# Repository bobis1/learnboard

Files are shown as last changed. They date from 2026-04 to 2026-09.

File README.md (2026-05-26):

# Learnboard
Learnboard is a midi keyboard that I designed to "get my foot through the door" of creating hardware projects. This keyboard has 8 keys(16 physical switches). This keyboard has the feature to load "songs" into it. This keyboard also has LEDs that are under each of the 8 keys. These will light up whenyou hit the key or if the song that is loaded requires it.

## Features
* Freeplay mode
* Song loading/play-along mode
* Key Acceleration detection

## PCB
The learnboard's PCB has 2 layers.
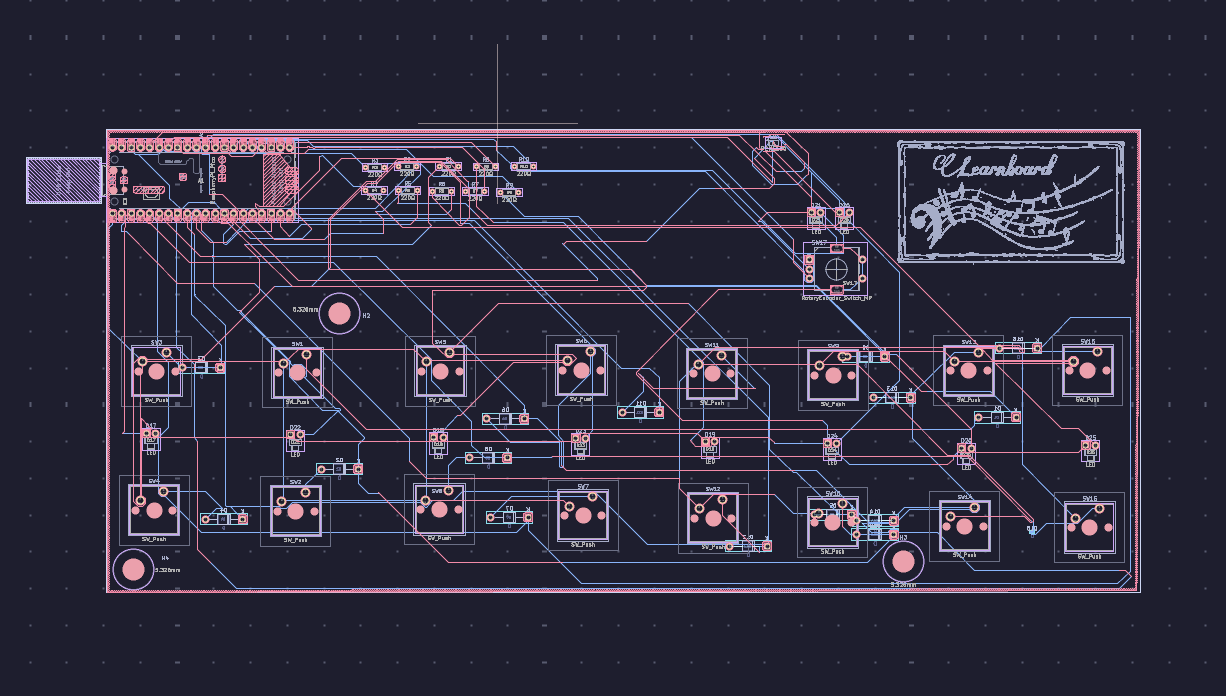
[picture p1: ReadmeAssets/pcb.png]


Here is the schematic for the PCB
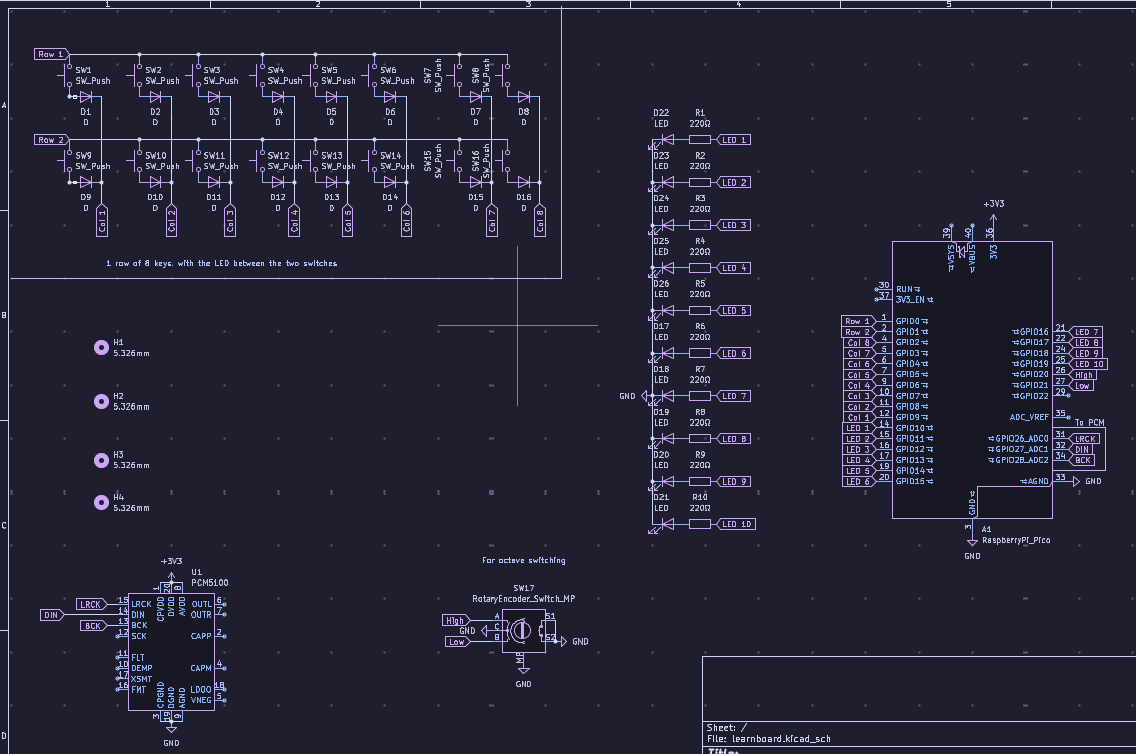
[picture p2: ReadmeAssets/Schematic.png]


Here is a 3D model of the pcb
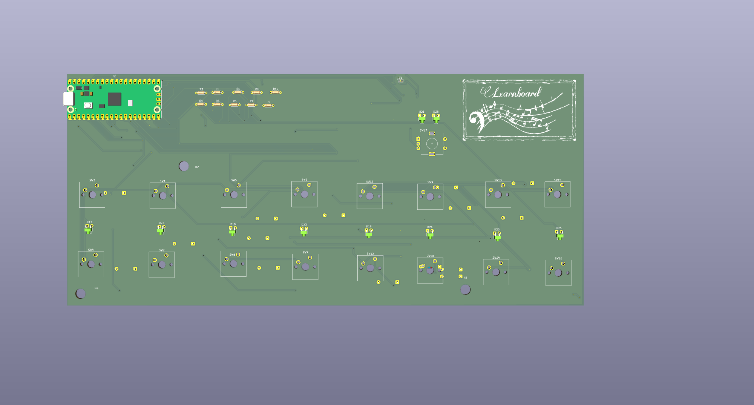
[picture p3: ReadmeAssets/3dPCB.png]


## Usage
To use the learnboard in the most basic context you simply hit the keys and the corresponding LED on that key will light up. To use the non freeplay mode you must use the webui that is inside the respective folder(This is a html document). From there you can adjust many things with the learnboard(Such as volume). The song loading works by loading .json files through the webui. To connect the midi keyboard to the webui you have to connect the midi keyboard to your computer. Then click the connect button on the connect window(These windows are partially based on the webos jam).

## Flashing
You can get the firmwware from the firmware folder of the repo. For this you can follow the circuit python tutorial for the board here: https://circuitpython.org/board/raspberry_pi_pico/ .

## Assembly
(When I actually have everything I will have images)
To assemble the learnboard you must first 3d print the case along with it's connectors. You need to print both parts of Case.step and caseTop.step. You need to print 2 Connector.step parts and 2 ConnectorWedge.step parts(This is if you are using printed connectors to connect the top and bottom of the case). You need 4 prints of teh PrintConnector.step file. When you have these printed slot the PrintConnectors into their respective bowtie slots in the cases.
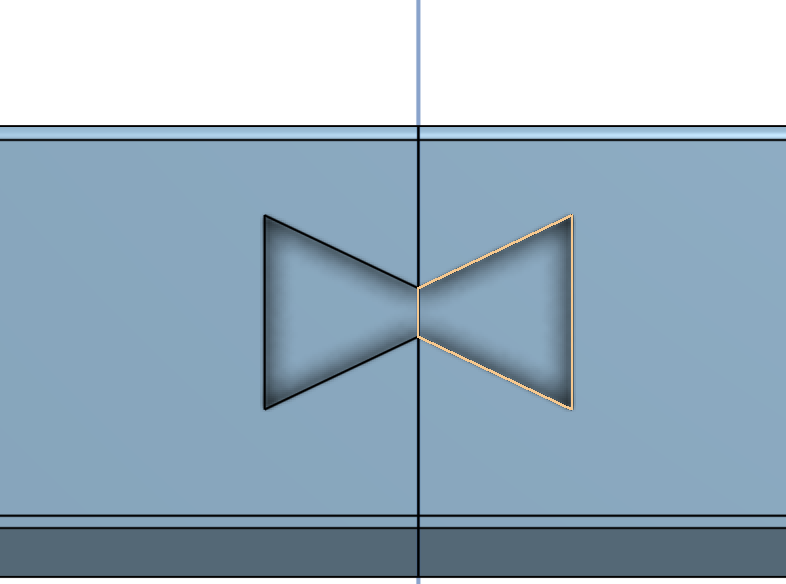
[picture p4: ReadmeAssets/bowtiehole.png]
(Looks like this). If you are using the printed connectors slot the Connector.step results into the two holes on the cases.Then put the wedge up the fork of the connector.

## Case
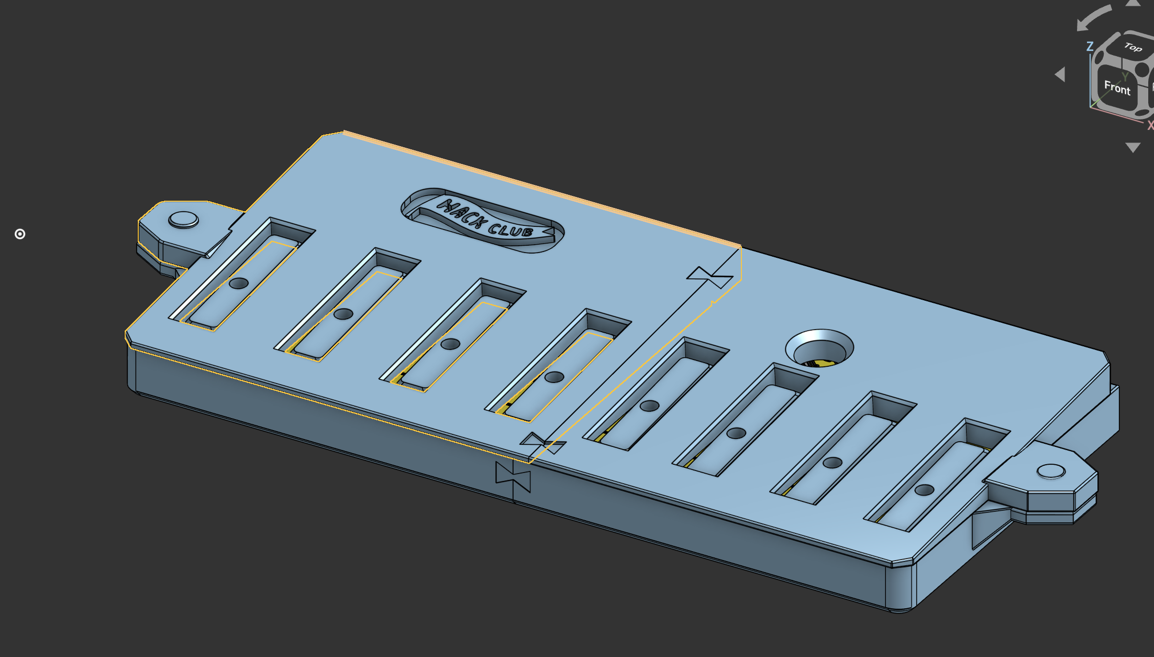
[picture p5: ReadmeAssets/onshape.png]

The case can be printed in several pieces. To hold the case pieces that are printed seperately there are "bowtie" connectors to connect these. The connector for the case top and the case bottom can be printed however a machine screw can also be used for that purpose. The .step files will be in the CAD folder. When printing I split the case into four parts. Two of the parts are in the Case.step file and the other two are in the caseTop.step file
Here is the link to the onshape.
https://cad.onshape.com/documents/c06ae8a09bf7d6a8ae56adf7/w/ad5690a7cddb318995ea60e9/e/03d033c41fe9f6e94a9a3737

## BOM
Here is the BOM. I put n/a in place of anything that I already had.
| Id | Designator | Footprint | Quantity | Designation | Supplier and ref | Unit price | Total price |  | Component | Price |
| --- | --- | --- | --- | --- | --- | --- | --- | --- | --- | --- |
| 1 | D19,D18,D22,D25,D21,D23,D24,D26,D17,D20 | LED_D1.8mm_W1.8mm_H2.4mm_Horizontal_O1.27mm_Z1.6mm | 10 | LED | https://www.aliexpress.us/item/3256802958597906.html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 | $0.99 | $0.99 |  | LED | $0.99 |
| 2 | SW9,SW15,SW14,SW4,SW8,SW2,SW16,SW5,SW13,SW10,SW1,SW6,SW3,SW11,SW7,SW12 | SW_Cherry_MX_1.00u_PCB | 16 | SW_Push | https://www.adafruit.com/product/4955 | $0.70 | $12.65 |  | Key Switches | $12.65 |
| 3 | R10,R7,R2,R6,R5,R9,R8,R3,R1,R4 | R_Axial_DIN0204_L3.6mm_D1.6mm_P5.08mm_Horizontal | 10 | 220Ω | https://www.aliexpress.us/item/3256811723963477.html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 | $0.99 | $0.99 |  | Resistor | $0.99 |
| 4 | A1 | RaspberryPi_Pico_Common_Unspecified | 1 | RaspberryPi_Pico | https://www.sparkfun.com/raspberry-pi-pico.html?src=raspberrypii | $4.60 | $4.60 |  | Raspberry pi_pico | $4.60 |
| 5 | U1 | TSSOP-20_4.4x6.5mm_P0.65mm | 1 | PCM5100 | https://www.adafruit.com/product/6251 | $3.95 | $3.95 |  | PCM5100 | $3.95 |
| 6 | SW17 | RotaryEncoder_Alps_EC11E-Switch_Vertical_H20mm | 1 | RotaryEncoder_Switch_MP | https://www.aliexpress.us/item/3256805796844720.html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 | $0.99 | $0.99 |  | Rotary Encoder | $0.99 |
| 7 | D12,D11,D8,D7,D13,D3,D6,D16,D10,D15,D14,D4,D1,D9,D2,D5 | D_0201_0603Metric_Pad0.64x0.40mm_HandSolder | 16 | D | https://www.aliexpress.us/item/3256807405706559.html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 | $0.11 | $2.10 |  | Diodes | $2.10 |
|  |  |  |  |  |  |  |  |  | PCB | $18.20 |
|  |  |  |  |  |  |  |  |  | Shipping | $22.19 |
|  |  |  |  |  |  |  |  |  | Total | $65.67 |
The .csv file for the BOM can be found [here](ReadmeAssets/BOM.csv)

### Poster
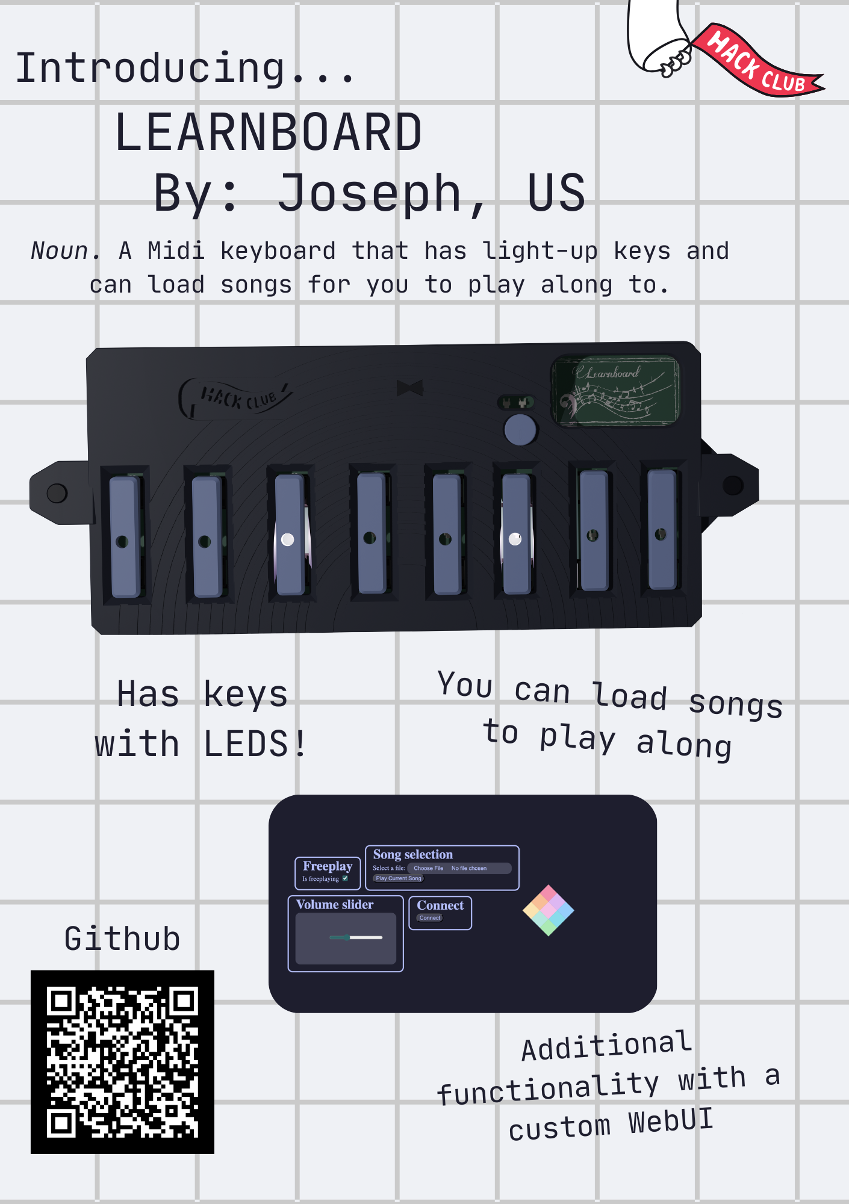
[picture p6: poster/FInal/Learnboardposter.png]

The .pdf file for the poster can be found [here](poster/Learnboardposter.pdf)

## References
https://blueprint.hackclub.com/starter-projects/midi
This is a project I got alot of the idea from.
https://jams.hackclub.com/batch/webOS
Where I got the ideas for the windows from

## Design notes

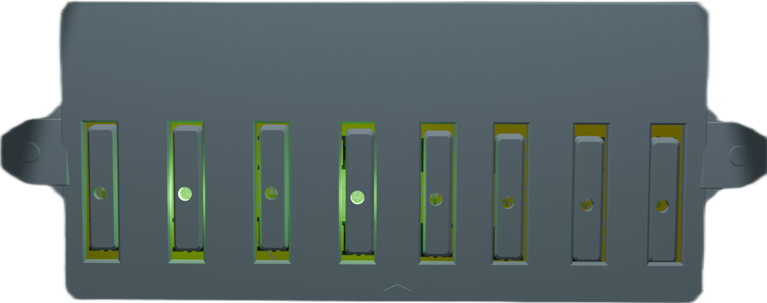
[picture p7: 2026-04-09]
poster/DraftRenders/FinalTrans.png

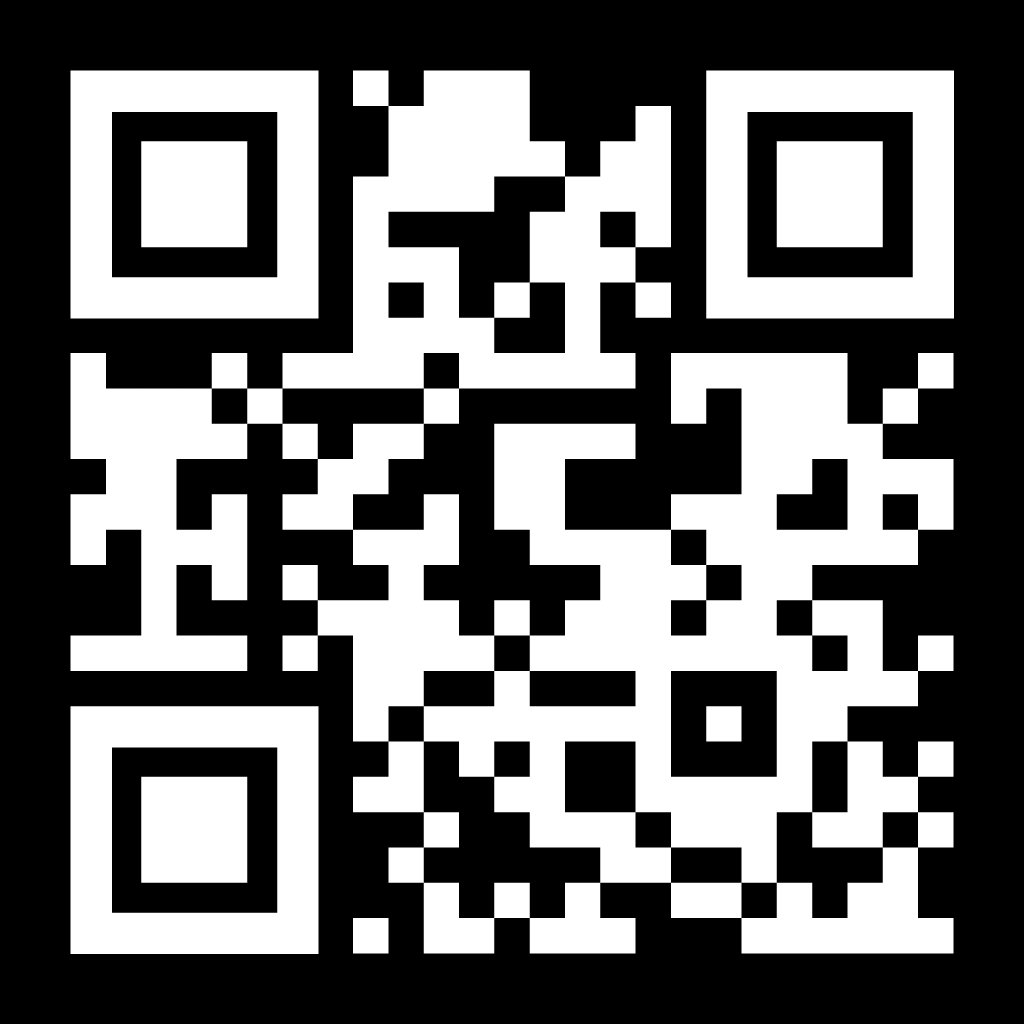
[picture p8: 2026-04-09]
poster/Posterassets/qr.png

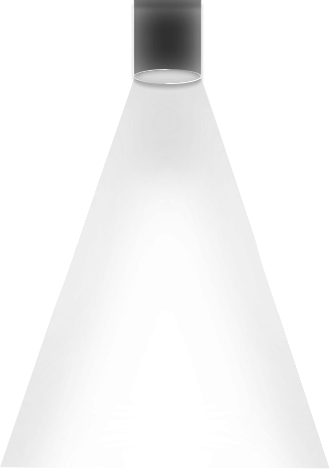
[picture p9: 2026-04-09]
poster/Posterassets/Light.png

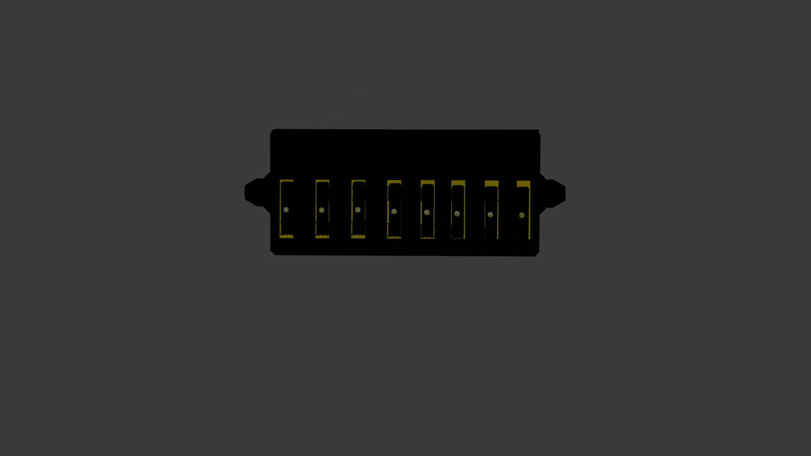
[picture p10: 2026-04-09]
poster/DraftRenders/Untitled.png

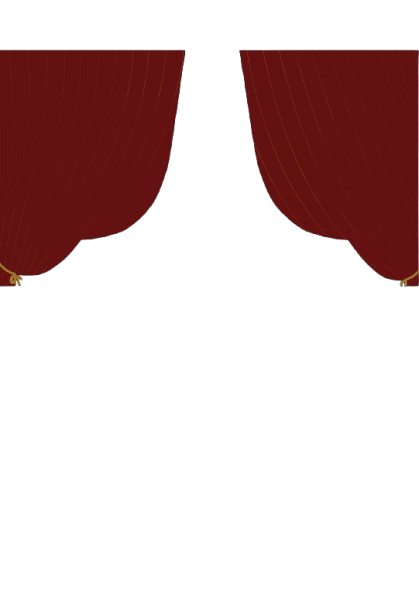
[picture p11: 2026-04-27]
poster/Posterassets/Learnboard_poster-removebg-preview.png

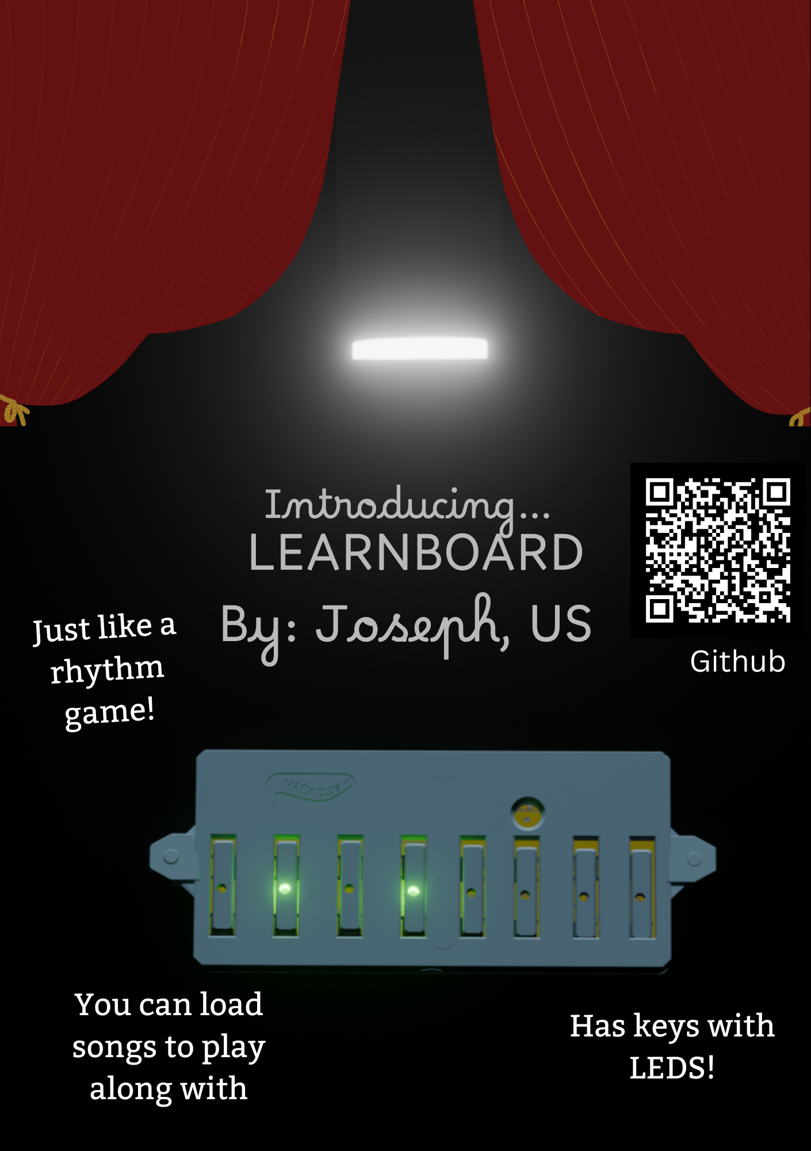
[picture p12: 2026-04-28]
poster/DraftRenders/Learnboardposter.png

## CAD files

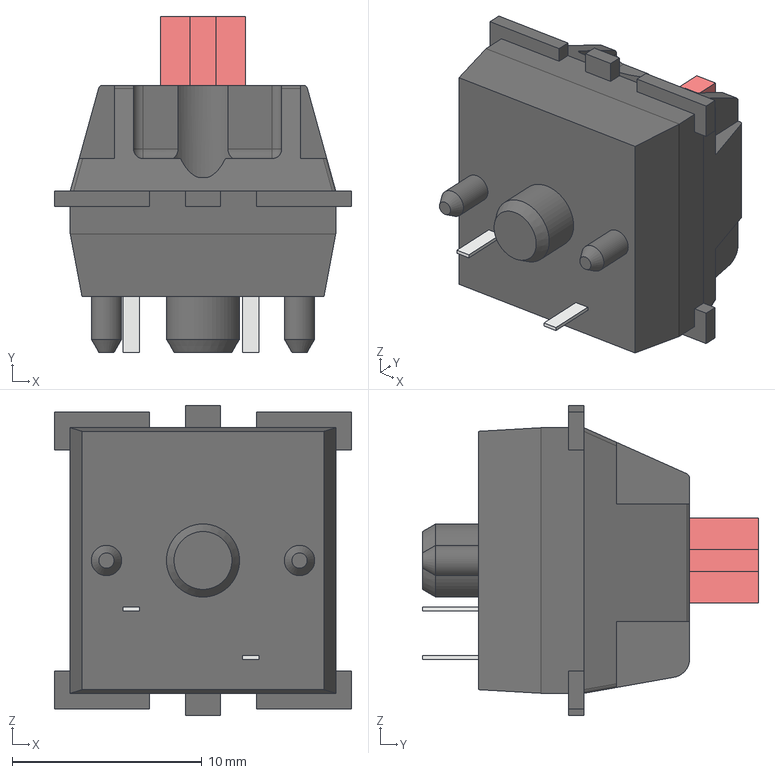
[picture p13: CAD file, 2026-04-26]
PCB/switch.step
15.6 x 17.7 x 16.3 mm

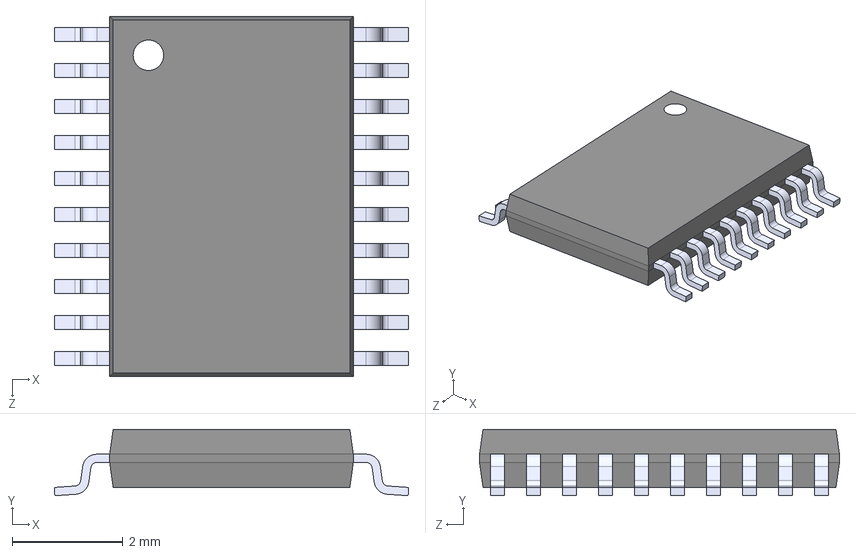
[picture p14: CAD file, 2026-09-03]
PCM5100APWR/PCM5100APWR.step
6.40 x 1.20 x 6.50 mm

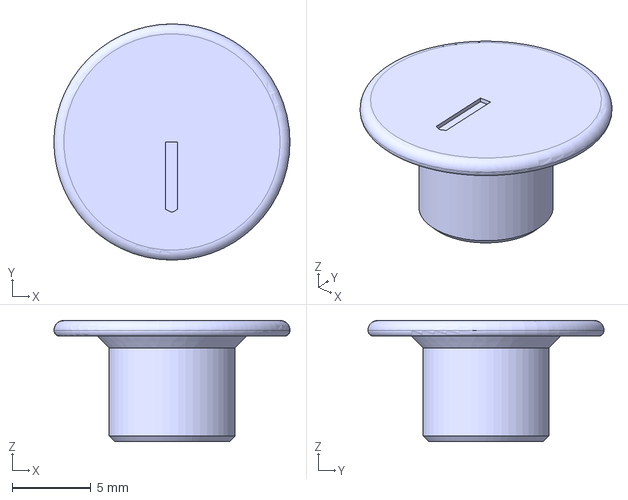
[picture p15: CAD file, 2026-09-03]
stepFiles/RotaryEncoderTop.step
15.0 x 15.0 x 7.70 mm

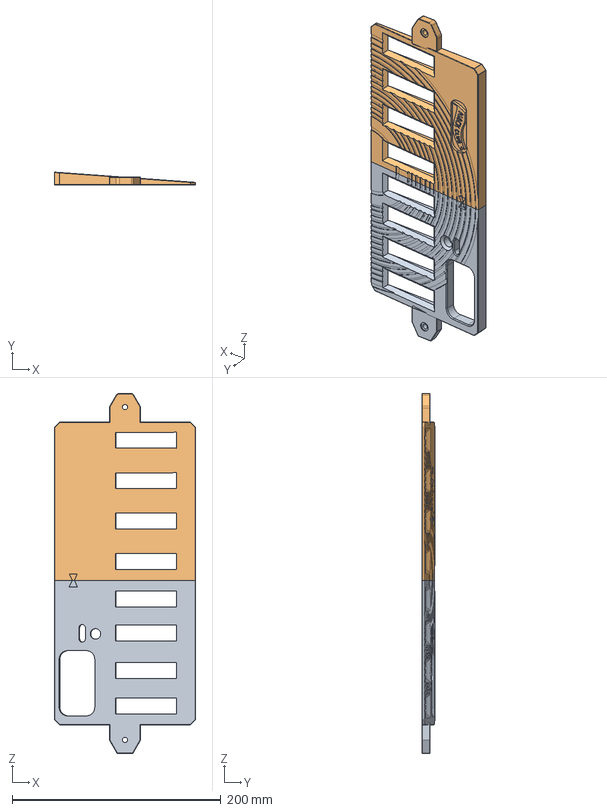
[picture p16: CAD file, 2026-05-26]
stepFiles/CaseTop.step
135.4 x 12.2 x 344.7 mm

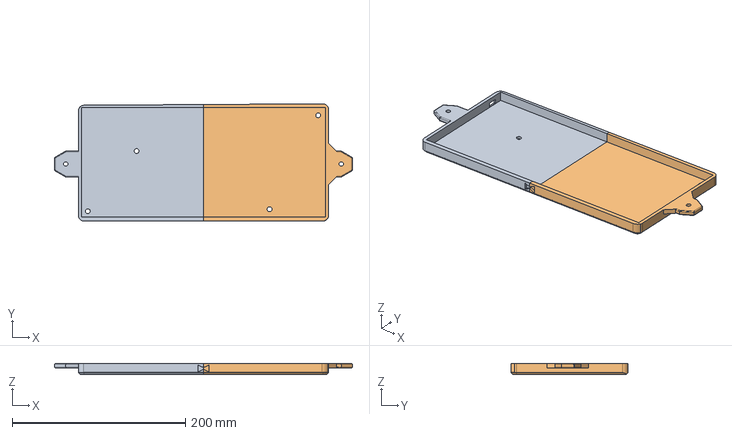
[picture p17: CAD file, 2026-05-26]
stepFiles/Case.step
344.1 x 135.5 x 12.5 mm

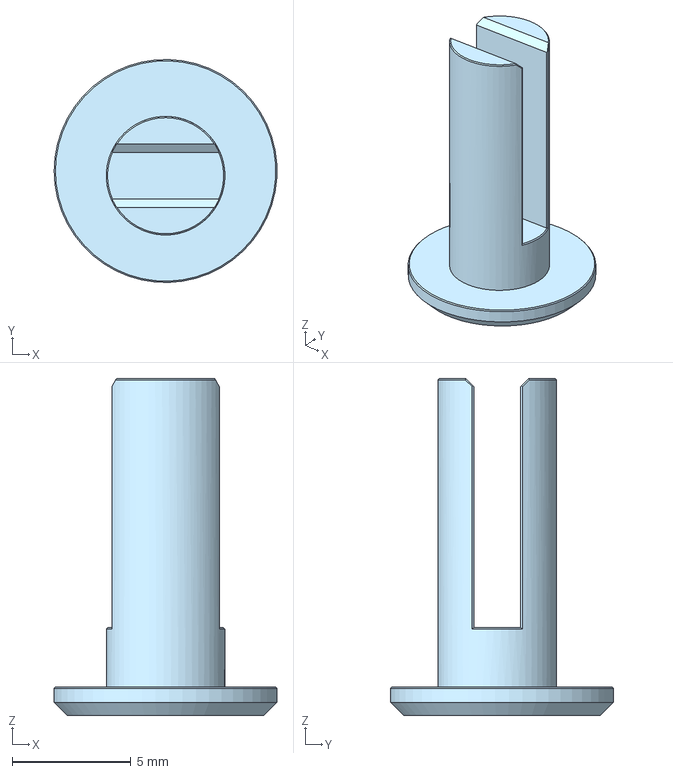
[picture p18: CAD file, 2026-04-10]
stepFiles/Connector.step
9.39 x 9.39 x 14.2 mm

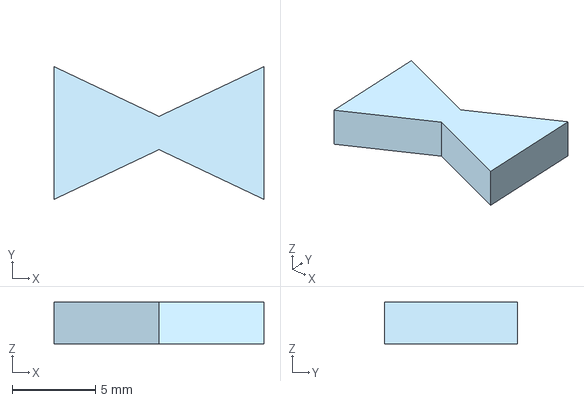
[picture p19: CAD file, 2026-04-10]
stepFiles/PrintConnector.step
12.6 x 8.00 x 2.50 mm

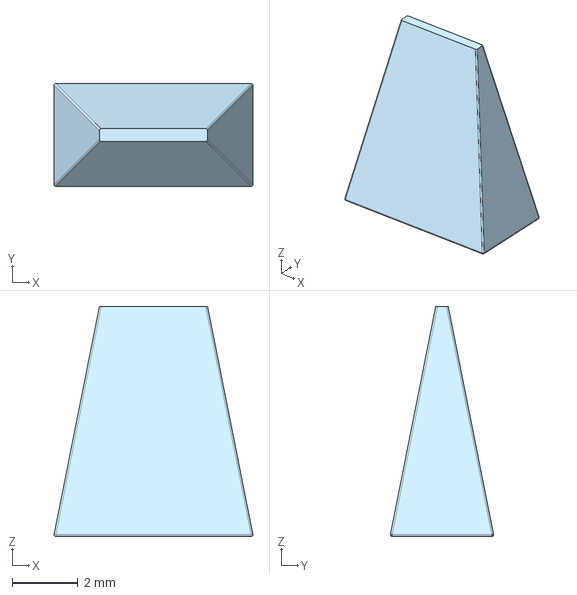
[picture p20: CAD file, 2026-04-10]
stepFiles/ConnectorWedge.step
6.05 x 3.14 x 7.00 mm

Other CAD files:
poster/LightRender.blend
stepFiles/Case.3mf
stepFiles/CaseTop.3mf
stepFiles/RotaryEncoderTop.3mf

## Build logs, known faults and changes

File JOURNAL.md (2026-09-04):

---
title: "Learnboard-build"
author: "Bobis"
description: "a midi keyboard that has the keys light up when you play them"
created_at: "2026-04-2"
---

# September 2: Sodered some of the basic components.

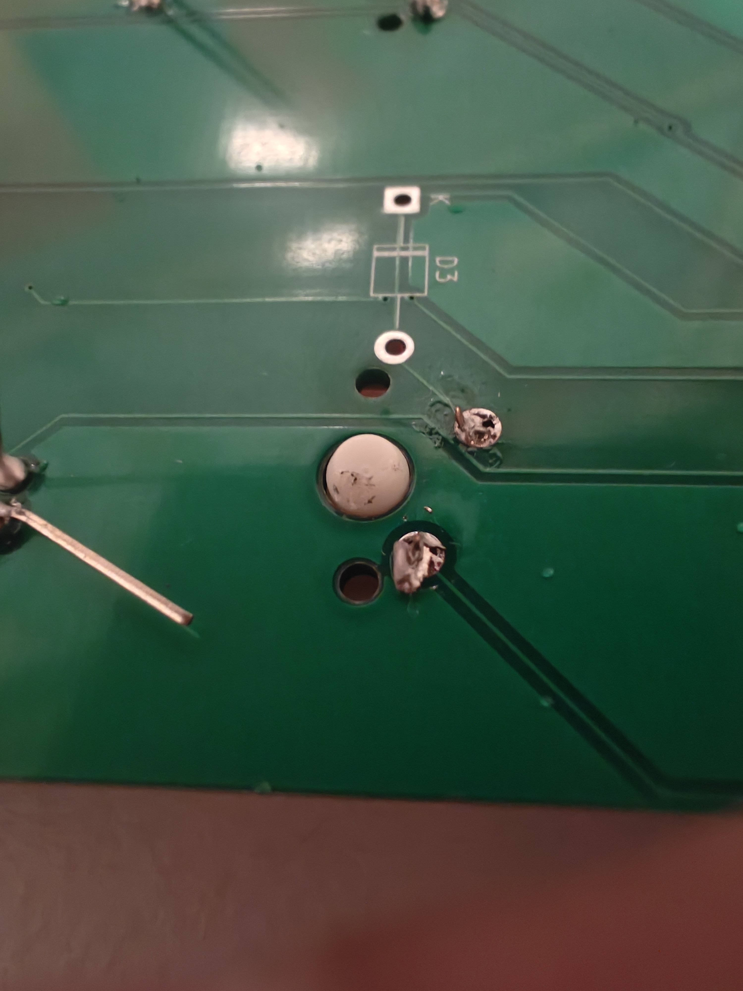
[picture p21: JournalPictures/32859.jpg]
BurntKeyswitch
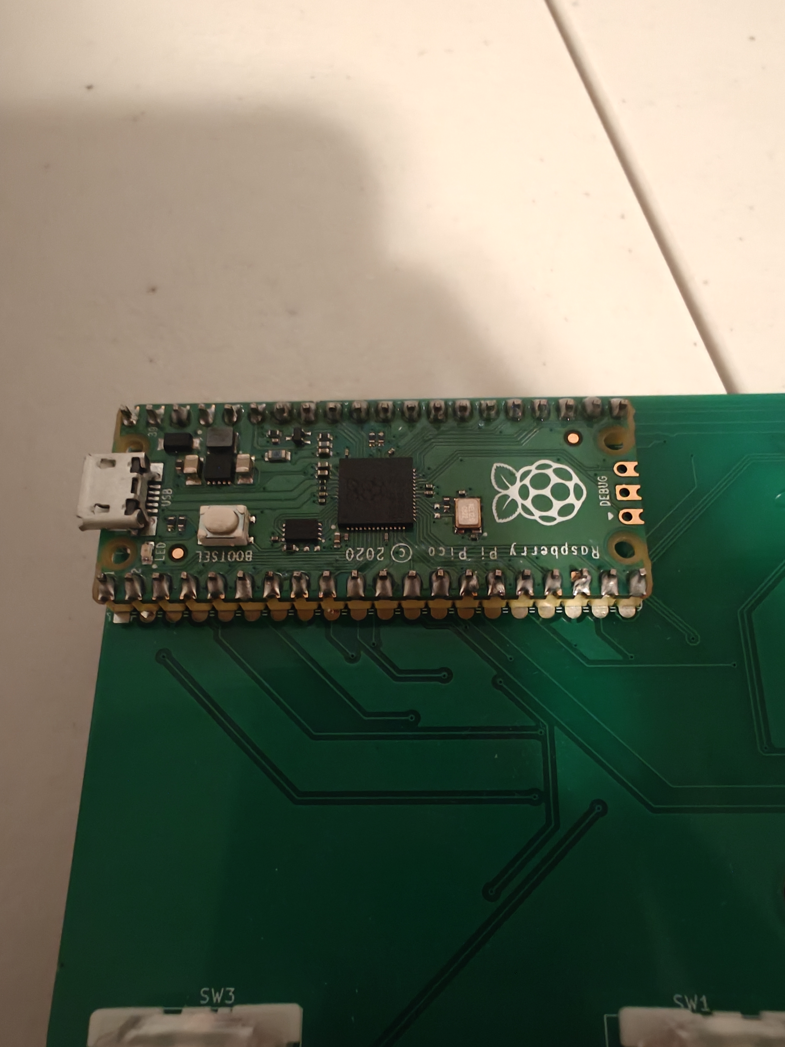
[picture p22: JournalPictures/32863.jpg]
rpPico
This devlog I worked on trying to soder all the components onto the pcb. This is my first time sodering so it did not go the best. I partially burnt one of the key switches, oops. . The resistors were very messy as well with the the footprint being too small to actually fit the resistor properly. The other than this I feel like my sodering on the raspberry pi pico was good enough that . Overall, this is not too bad. I really need to be more efficient in my time though.

-Recording links
https://lapse.hackclub.com/timelapse/0V47lkOwijM5
https://lapse.hackclub.com/timelapse/Xaw-gElLUrd_
https://lapse.hackclub.com/timelapse/J6UoXvX0RNCo
https://lapse.hackclub.com/timelapse/zv9pdq6mI1ch
https://lapse.hackclub.com/timelapse/Xwd5ic2uPJUL

**Total time spent: 1.56 hours**

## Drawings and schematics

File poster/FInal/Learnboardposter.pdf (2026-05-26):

Introducing...

# LEARNBOARD

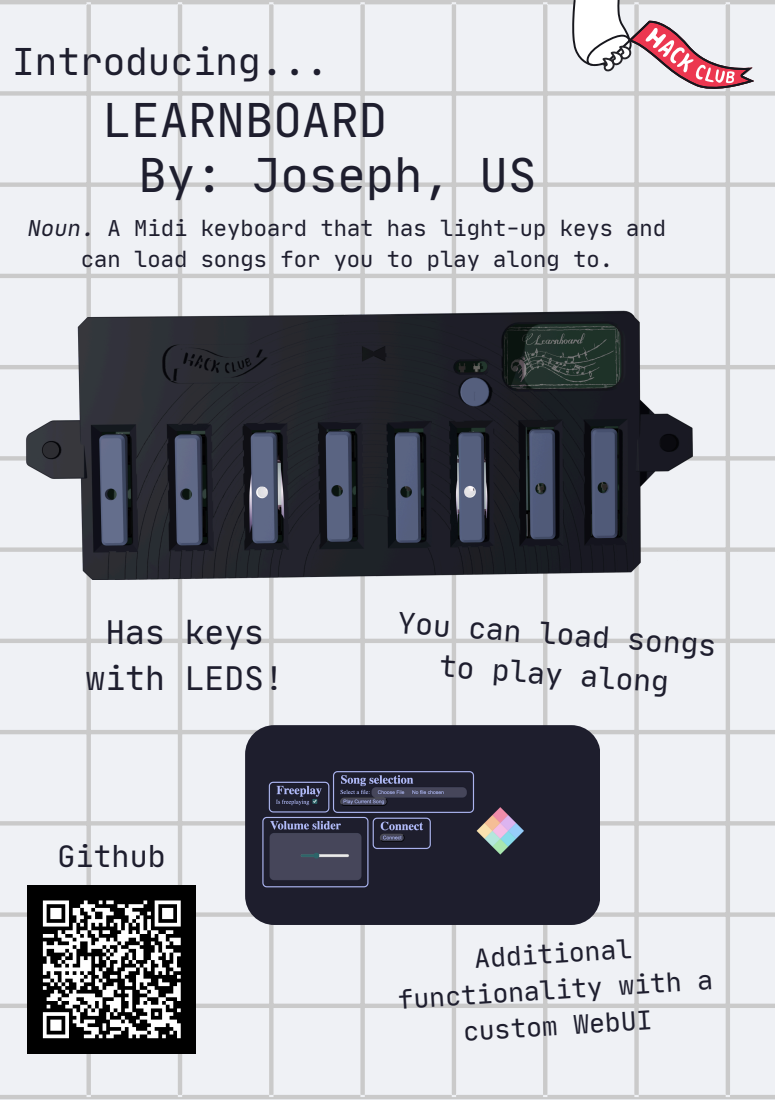
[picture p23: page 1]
By: Joseph,; Github; Additional functionality with a custom WebUI; Has; keys; with; LEDS!; Noun. A Midi keyboard that has light-up; keys and; can load songs; for you to play along to.

You can load songs

to play along

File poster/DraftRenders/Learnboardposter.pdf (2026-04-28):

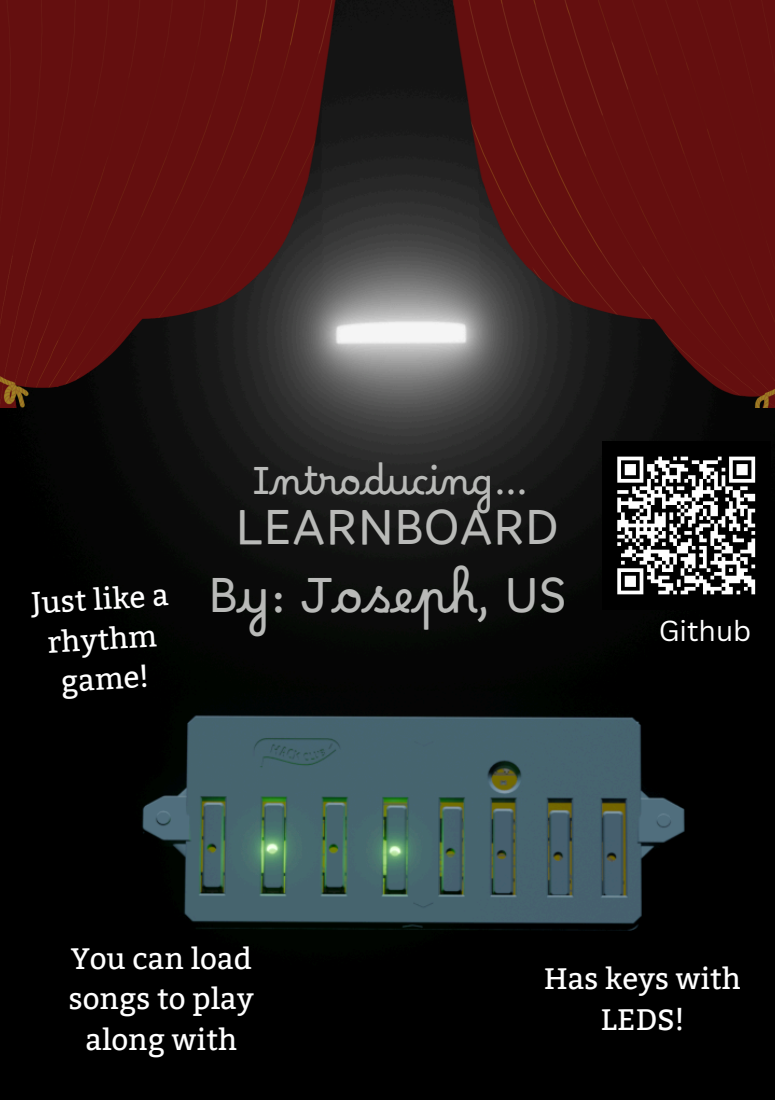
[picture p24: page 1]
Github; Just like a rhythm game!

Introducing...
LEARNBOARD
By: Joseph, US

You can load
songs to play
along with

Has keys with
LEDS!

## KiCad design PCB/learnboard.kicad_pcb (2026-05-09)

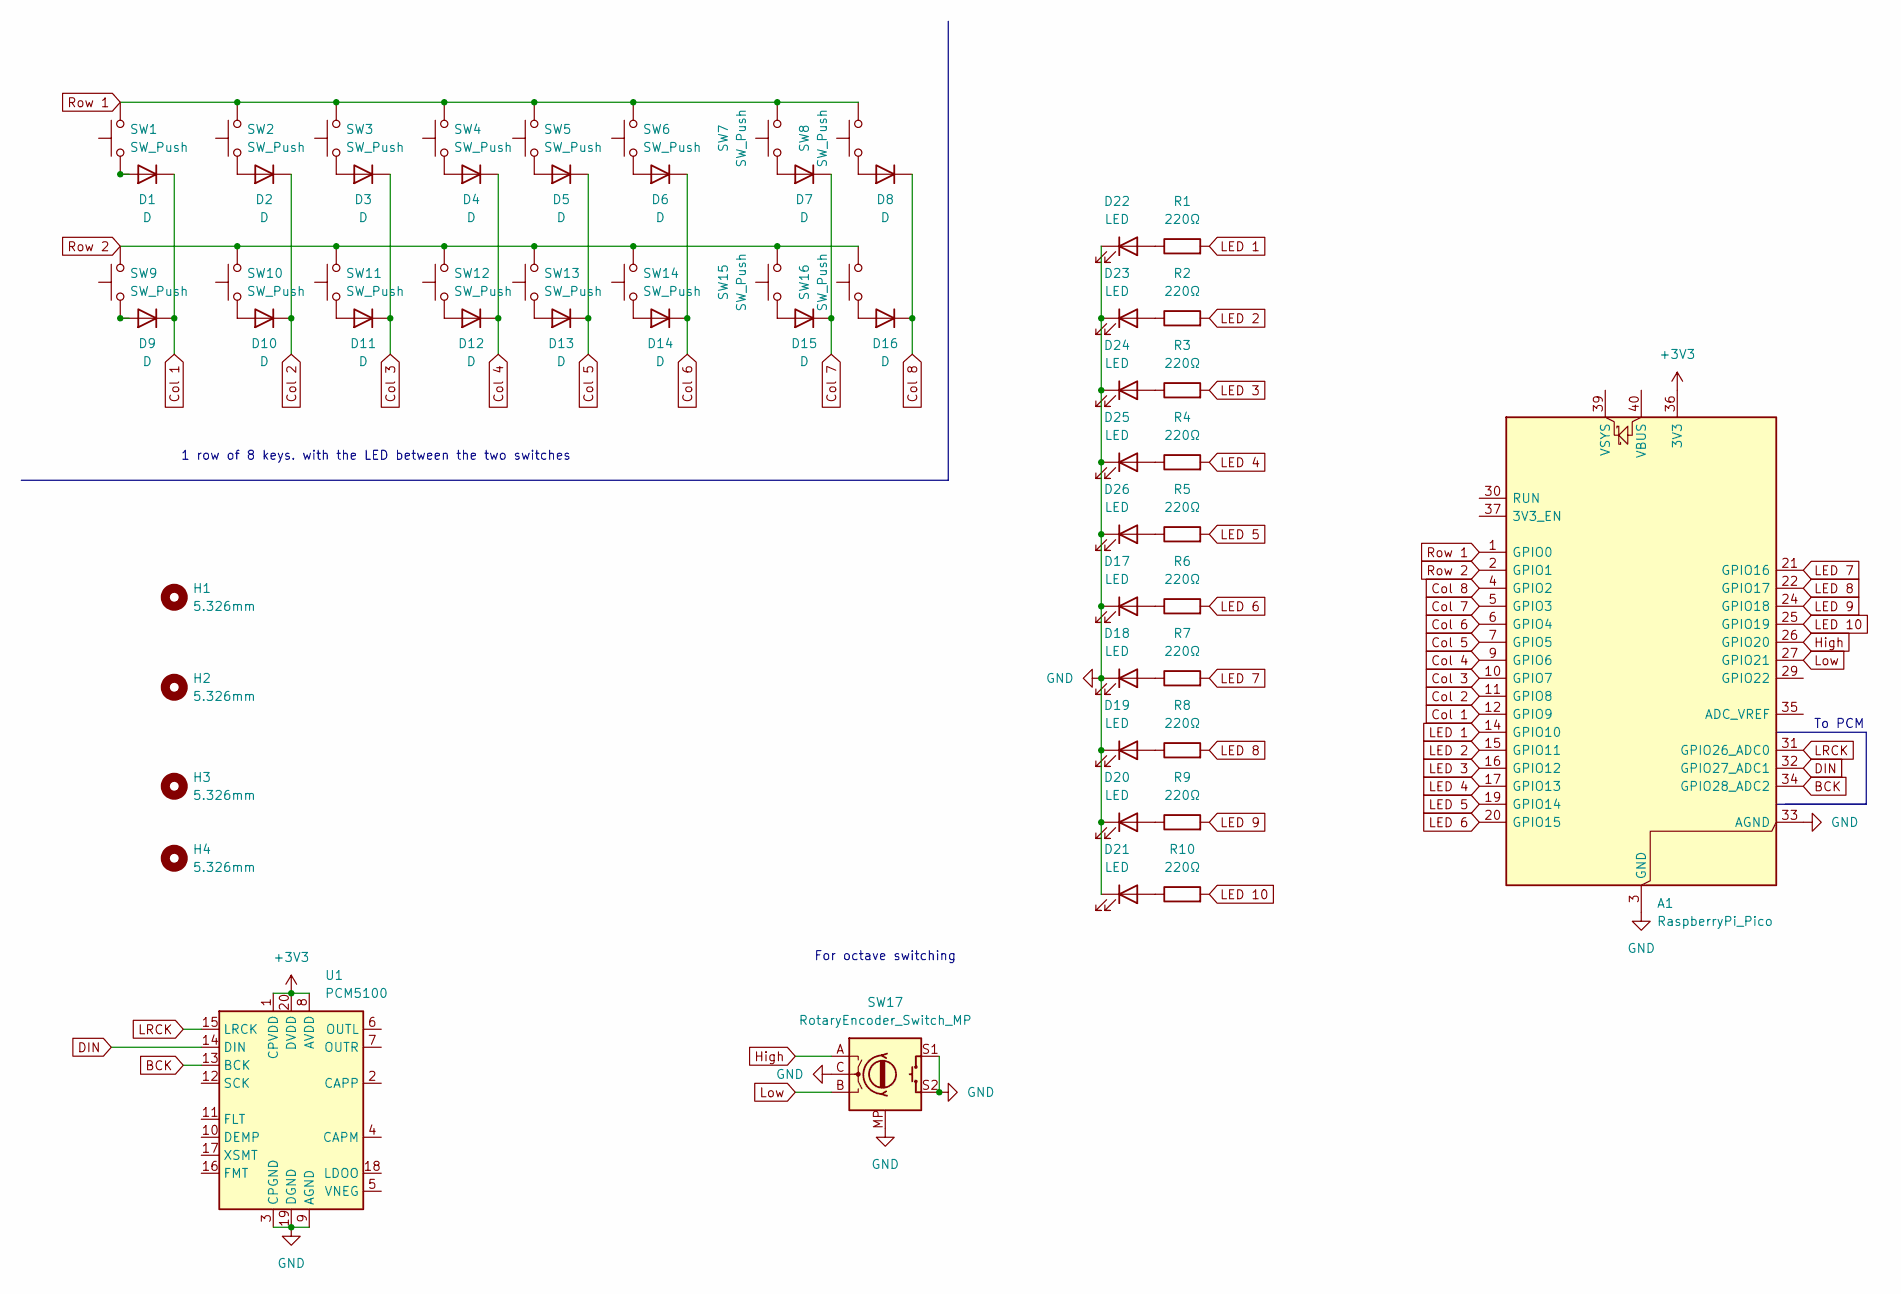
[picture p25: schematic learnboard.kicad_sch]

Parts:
A1: RaspberryPi_Pico; RaspberryPi_Pico_Common_Unspecified
D1, D2, D3, D4, D5, D6, D7, D8, D9, D10, D11, D12, D13, D14, D15, D16: D; D_0201_0603Metric
D17, D18, D19, D20, D21, D22, D23, D24, D25, D26: LED; LED_D1.8mm_W1.8mm_H2.4mm_Horizontal_O1.27mm_Z1.6mm
H1, H2, H3, H4: 5.326mm; MountingHole_5.5mm
R1, R2, R3, R4, R5, R6, R7, R8, R9, R10: 220Ω; R_Axial_DIN0204_L3.6mm_D1.6mm_P5.08mm_Horizontal
SW1, SW2, SW3, SW4, SW5, SW6, SW7, SW8, SW9, SW10, SW11, SW12, SW13, SW14, SW15, SW16: SW_Push; SW_Cherry_MX_1.00u_PCB
SW17: RotaryEncoder_Switch_MP; RotaryEncoder_Alps_EC11E-Switch_Vertical_H20mm
U1: PCM5100; Nexperia_WLCSP-15_2.37x1.17mm_Layout6x3_P0.4mmP0.8mm

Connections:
+3V3: A1.36 (3V3), U1.1 (CPVDD), U1.8 (AVDD), U1.20 (DVDD)
BCK: A1.34 (GPIO28_ADC2), U1.13 (BCK)
Col 1: A1.12 (GPIO9), D1.1 (K), D9.1 (K)
Col 2: A1.11 (GPIO8), D2.1 (K), D10.1 (K)
Col 3: A1.10 (GPIO7), D3.1 (K), D11.1 (K)
Col 4: A1.9 (GPIO6), D4.1 (K), D12.1 (K)
Col 5: A1.7 (GPIO5), D5.1 (K), D13.1 (K)
Col 6: A1.6 (GPIO4), D6.1 (K), D14.1 (K)
Col 7: A1.5 (GPIO3), D7.1 (K), D15.1 (K)
Col 8: A1.4 (GPIO2), D8.1 (K), D16.1 (K)
DIN: A1.32 (GPIO27_ADC1), U1.14 (DIN)
GND: A1.3 (GND), A1.8 (GND), A1.13 (GND), A1.18 (GND), A1.23 (GND), A1.28 (GND), A1.33 (AGND), A1.38 (GND), D17.1 (K), D18.1 (K), D19.1 (K), D20.1 (K), D21.1 (K), D22.1 (K), D23.1 (K), D24.1 (K), D25.1 (K), D26.1 (K), SW17.C, SW17.MP, SW17.S1, SW17.S2, U1.3 (CPGND), U1.9 (AGND), U1.19 (DGND)
High: A1.26 (GPIO20), SW17.A
LED 1: A1.14 (GPIO10), R1.2
LED 2: A1.15 (GPIO11), R2.2
LED 3: A1.16 (GPIO12), R3.2
LED 4: A1.17 (GPIO13), R4.2
LED 5: A1.19 (GPIO14), R5.2
LED 6: A1.20 (GPIO15), R6.2
LED 7: A1.21 (GPIO16), R7.2
LED 8: A1.22 (GPIO17), R8.2
LED 9: A1.24 (GPIO18), R9.2
LED 10: A1.25 (GPIO19), R10.2
LRCK: A1.31 (GPIO26_ADC0), U1.15 (LRCK)
Low: A1.27 (GPIO21), SW17.B
unnamed: D1.2 (A), SW1.1
unnamed: D2.2 (A), SW2.1
unnamed: D3.2 (A), SW3.1
unnamed: D4.2 (A), SW4.1
unnamed: D5.2 (A), SW5.1
unnamed: D6.2 (A), SW6.1
unnamed: D7.2 (A), SW7.1
unnamed: D8.2 (A), SW8.1
unnamed: D9.2 (A), SW9.1
unnamed: D10.2 (A), SW10.1
unnamed: D11.2 (A), SW11.1
unnamed: D12.2 (A), SW12.1
unnamed: D13.2 (A), SW13.1
unnamed: D14.2 (A), SW14.1
unnamed: D15.2 (A), SW15.1
unnamed: D16.2 (A), SW16.1
unnamed: D17.2 (A), R6.1
unnamed: D18.2 (A), R7.1
unnamed: D19.2 (A), R8.1
unnamed: D20.2 (A), R9.1
unnamed: D21.2 (A), R10.1
unnamed: D22.2 (A), R1.1
unnamed: D23.2 (A), R2.1
unnamed: D24.2 (A), R3.1
unnamed: D25.2 (A), R4.1
unnamed: D26.2 (A), R5.1
Row 1: A1.1 (GPIO0), SW1.2, SW2.2, SW3.2, SW4.2, SW5.2, SW6.2, SW7.2, SW8.2
Row 2: A1.2 (GPIO1), SW9.2, SW10.2, SW11.2, SW12.2, SW13.2, SW14.2, SW15.2, SW16.2

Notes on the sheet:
To PCM
For octave switching
1 row of 8 keys. with the LED between the two switches

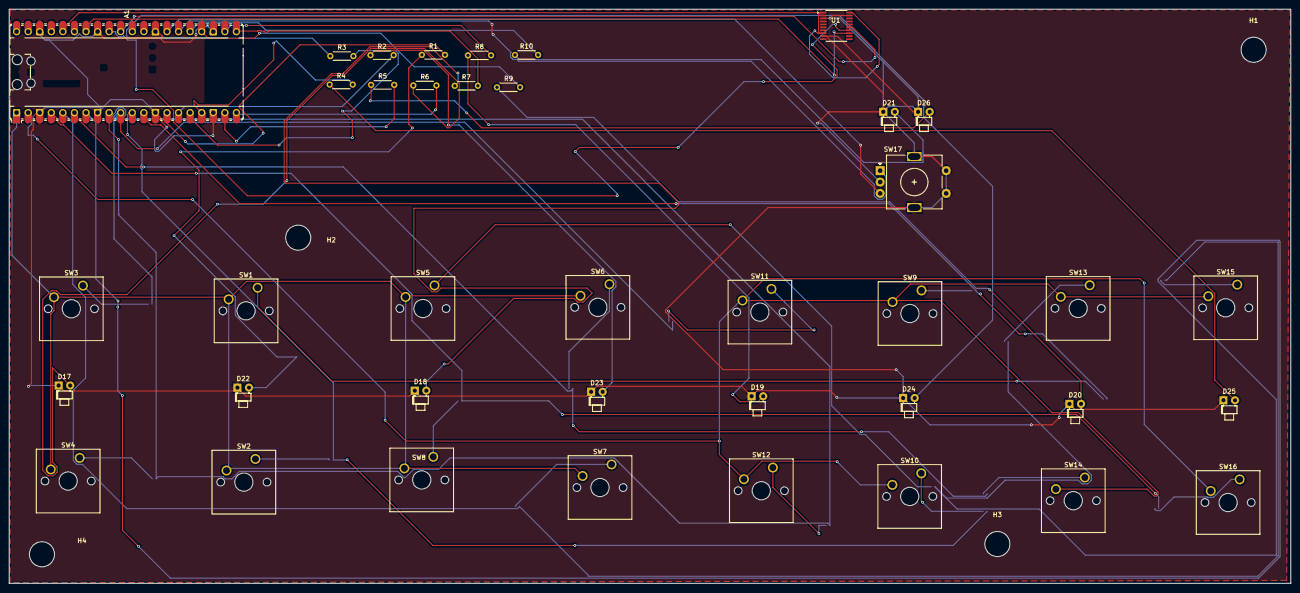
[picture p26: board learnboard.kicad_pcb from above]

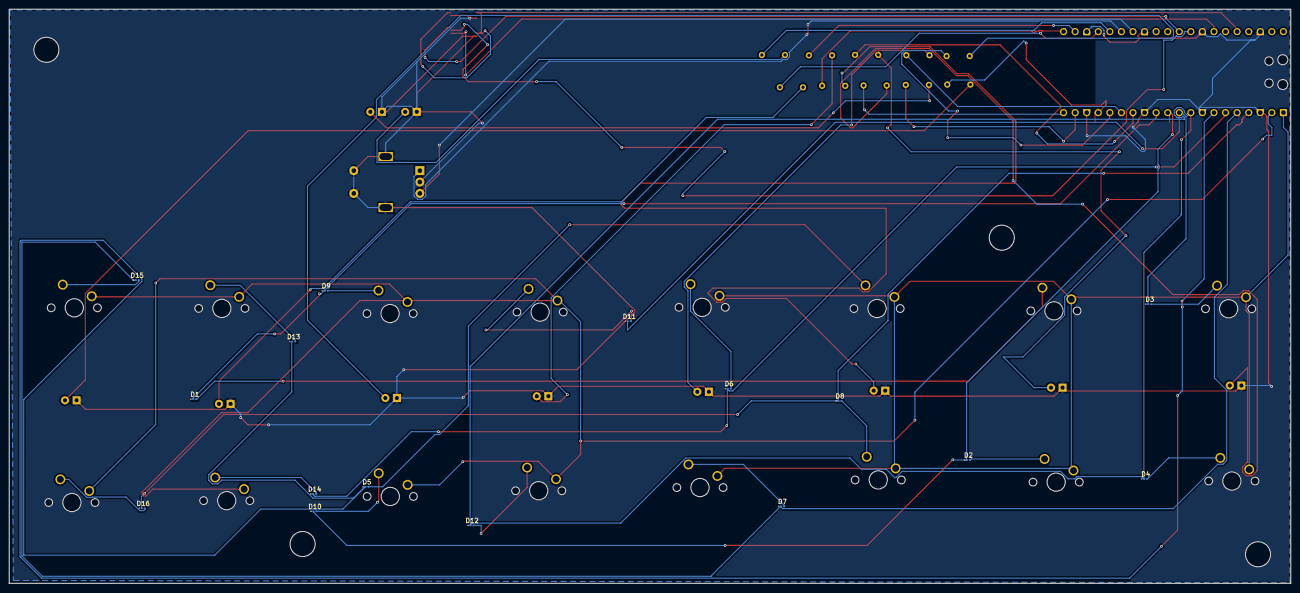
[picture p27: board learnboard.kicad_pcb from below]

Board: 2 copper layers, 281.4 x 126.0 mm, 59 parts (16 on the bottom side), 53 nets.

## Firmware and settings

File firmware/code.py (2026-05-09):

import board
import keypad
import digitalio
import audiobusio
import audiocore
import time
import rotaryio
import audiomixer
import usb_cdc

import usb_midi
import adafruit_midi
from adafruit_midi.note_off import NoteOff
from adafruit_midi.note_on import NoteOn
from adafruit_midi.pitch_bend import PitchBend

dac = audiobusio.I2SOut(bit_clock=board.GPIO1028_ADC2, word_select=board.GPIO1028_ADC0, data= board.GPIO1028_ADC1)
mixer = audiomixer.Mixer(voice_count=1, sample_rate=22050, channels=1, bits_per_sample=16, samples_per_frame=512)
dac.play(mixer)

rows = [board.GPIO100, board.GPIO101, board.GPIO102]
cols = [board.GPIO103, board.GPIO104, board.GPIO105, board.GPIO106, board.GPIO107, board.GPIO108, board.GPIO109]

wavef0 = open("pianoC", "rb")
wavef1 = open("pianoD", "rb")
wavef2 = open("pianoE", "rb")
wavef3 = open("pianoF", "rb")
wavef4 = open("pianoG", "rb")
wavef5 = open("pianoA", "rb")
wavef6 = open("pianoB", "rb")
wavef7 = open("pianoC1", "rb")

wav0 = audiocore.WaveFile(wavef0)
wav1 = audiocore.WaveFile(wavef1)
wav2 = audiocore.WaveFile(wavef2)
wav3 = audiocore.WaveFile(wavef3)
wav4 = audiocore.WaveFile(wavef4)
wav5 = audiocore.WaveFile(wavef5)
wav6 = audiocore.WaveFile(wavef6)
wav7 = audiocore.WaveFile(wavef7)

SW1 = 9
SW2 = 10
SW3 = 11
SW4 = 12
SW5 = 13
SW6 = 14
SW7 = 15
SW8 = 16
SW9 = 17
SW10 = 18
SW11 = 19
SW12 = 20
SW13 = 21
SW14 = 22
SW15 = 23
SW16 = 24

iswav0Playing = False
iswav1Playing = False
iswav2Playing = False
iswav3Playing = False
iswav4Playing = False
iswav5Playing = False
iswav6Playing = False
iswav7Playing = False

L = []

L.append(digitalio.DigitalInOut(board.GPIO10))
L.append(digitalio.DigitalInOut(board.GPIO11))
L.append(digitalio.DigitalInOut(board.GPIO12))
L.append(digitalio.DigitalInOut(board.GPIO13))
L.append(digitalio.DigitalInOut(board.GPIO14))
L.append(digitalio.DigitalInOut(board.GPIO15))
L.append(digitalio.DigitalInOut(board.GPIO16))
L.append(digitalio.DigitalInOut(board.GPIO17))
L.append(digitalio.DigitalInOut(board.GPIO18))
L.append(digitalio.DigitalInOut(board.GPIO19))


nextKeys = []
nextKeyTimes = []

i = 0

encoder = rotaryio.IncrementalEncoder(board.GPIO20, board.GPIO21)

Freeplay = True


ticks = 20.0

currentTime = time.monotonic()


playingTime = 0.2
accuracy = float


usb_cdc.enable(True)

startTimes = {}

KeyGroups = {
    9:7,
    10:18,
    11:19,
    12:20,
    13:21,
    14:22,
    15:23,
    16:24

}

KeyGroupsToLED = {
    1:5,
    2:0,
    3:6,
    4:1,
    5:7,
    6:2,
    7:8,
    8:3
}

matrix = keypad.KeyMatrix(row_pins=(board.GPIO100, board.GPIO101), column_pins=(board.GPIO109, board.GPIO108, board.GPIO107, board.GPIO106, board.GPIO105, board.GPIO104, board.GPIO103, board.GPIO102))

led_off_times = [0.0] * 10
last_activated_led = 0

while True:

    currentTime = time.monotonic()
    event = matrix.events.get()
    position = encoder.position

    if position != enc_pos:
        enc_pos = position
        volume = position/20.0
        volume = max(0.0, min(1.0, volume))
        mixer.voice.level = volume

    if usb_cdc.console.in_waiting > 1:
        raw_data = usb_cdc.console.readline()
        line = str(raw_data, "utf-8").strip()
        line = str(raw_data, "utf-8").strip()
        if line.startswith("V"):
            try:
                new_vol = float(line[1:]) / 100
                mixer.voice[0].level = new_vol
            except:
                pass
        if line.startswith("F"):
            try:
                Freeplay = bool(line[1:])
            except:
                pass
        if line.startswith("K"):
            try:
                #The user puts in key group
                keyGroup = int(line[1:])
                KeyGroupsToLED[keyGroup].value = True
            except:
                pass
        if line.startswith("T"):
            try:
                #user puts the time in seconds.
                duration = float(line[1:])
                nextKeyTimes[i] = duration + currentTime
            except:
                pass



    if Freeplay == False:
        for idx in range(len(L)):
            if led_off_times[idx] != 0 and currentTime >= led_off_times[idx]:
                L[idx].value = False
                led_off_times[idx] = 0


    if event:
        print(event.key_number, event.pressed)
        if Freeplay:
            match event.key_number:
                case 9:
                    if iswav0Playing == False:
                        L[5].value = True
                        startTimes[9] = time.monotonic()
                        #iswav0Playing = True
                case 10:
                    if iswav1Playing == False:
                        startTimes[10] = time.monotonic()
                        L[0].value = True
                        #iswav1Playing = True
                case 11:
                    if iswav2Playing == False:
                        L[6].value = True
                        startTimes[11] = time.monotonic()
                        #iswav2Playing = True
                case 12:
                    if iswav3Playing == False:
                        L[1].value = True
                        startTimes[12] = time.monotonic()
                        #iswav3Playing = True
                case 13:
                    if iswav4Playing == False:
                        L[7].value = True
                        startTimes[13] = time.monotonic()
                        #iswav4Playing = True
                case 14:
                    if iswav5Playing == False:
                        L[2].value = True
                        startTimes[14] = time.monotonic()
                       # iswav5Playing = True
                case 15:
                    if iswav6Playing == False:
                        L[8].value = True
                        startTimes[15] = time.monotonic()
                        #iswav6Playing = True
                case 16:
                    if iswav7Playing == False:
                        L[3].value = True
                        startTimes[16] = time.monotonic()
                       # iswav7Playing = True
                #Bottom Key Start
                case 17:
                    if iswav0Playing == False:
                        startTimes[17] = time.monotonic()
                        VelVolum = volume/(startTimes[17]-startTimes[9])
                        mixer.voice[0].level = VelVolum
                        mixer.play(wav0)
                        L[5].value = True
                        nWav0 = time.time()
                      #  iswav0Playing = True
                case 18:
                    if iswav1Playing == False:
                        startTimes[18] = time.monotonic()
                        VelVolum = volume/(startTimes[18]-startTimes[10])
                        mixer.voice[0].level = VelVolum
                        mixer.play(wav1)
                        L[0].value = True
                        nWav1 = time.time()
                      #  iswav1Playing = True
                case 19:
                    if iswav2Playing == False:
                        startTimes[19] = time.monotonic
                        VelVolum = volume/(startTimes[19]-startTimes[11])
                        mixer.voice[0].level = VelVolum
                        mixer.play(wav1)
                        L[6].value = True
                        nWav2 = time.time()
                    #   iswav2Playing = True
                case 20:
                    if iswav3Playing == False:
                        startTimes[20] = time.monotonic()
                        VelVolum = volume/(startTimes[20]-startTimes[12])
                        mixer.voice[0].level = VelVolum
                        mixer.play(wav3)
                        L[1].value = True
                        nWav3 = time.time()
                    #   iswav3Playing = True
                case 21:
                    if iswav4Playing == False:
                        startTimes[21] = time.monotonic()
                        VelVolum = volume/(startTimes[21]-startTimes[13])
                        mixer.voice[0].level = VelVolum
                        mixer.play(wav4)
                        L[7].value = True
                        nWav4 = time.time()
                    #    iswav4Playing = True
                case 22:
                    if iswav5Playing == False:
                        startTimes[22] = time.monotonic()
                        VelVolum = volume/(startTimes[22]-startTimes[14])
                        mixer.voice[0].level = VelVolum
                        mixer.play(wav5)
                        L[2].value = True
                        nWav5 = time.time()
                    #    iswav5Playing = True
                case 23:
                    if iswav6Playing == False:
                        startTimes[23] = time.monotonic()
                        VelVolum = volume/(startTimes[23]-startTimes[15])
                        mixer.voice[0].level = VelVolum
                        mixer.play(wav6)
                        L[8].value = True
                        startTimes[23] = time.monotonic()
                        nWav6 = time.time()
                    #    iswav6Playing = True
                case 24:
                    if iswav7Playing == False:
                        startTimes[24] = time.monotonic()
                        VelVolum = volume/(startTimes[24]-startTimes[16])
                        mixer.voice[0].level = VelVolum
                        mixer.play(wav7)
                        L[3].value = True
                        nWav7 = time.time()
                      #  iswav7Playing = True
                case _:
                    print("unknown")
        if iswav0Playing:
            currTime = time.time() - nWav0;
            if currTime >= playingTime:
                mixer.stop(wav0)
                L[5].value = False

        if iswav1Playing:
            currTime = time.time() - nWav1;
            if currTime >= playingTime:
                mixer.stop(wav1)
                L[0].value = False

        if iswav2Playing:
            currTime = time.time() - nWav2;
            if currTime >= playingTime:
                mixer.stop(wav2)
                L[6].value = False
        if iswav3Playing:
            currTime = time.time() - nWav3;
            if currTime >= playingTime:
                mixer.stop(wav3)
                L[1].value = False
        if iswav4Playing:
            currTime = time.time() - nWav4;
            if currTime >= playingTime:
                mixer.stop(wav4)
                L[7].value = False
        if iswav5Playing:
            currTime = time.time() - nWav5;
            if currTime >= playingTime:
                mixer.stop(wav5)
                L[2].value = False
        if iswav6Playing:
            currTime = time.time() - nWav6;
            if currTime >= playingTime:
                mixer.stop(wav6)
                L[8].value = True
        if iswav7Playing:
            currTime = time.time() - nWav7;
            if currTime >= playingTime:
                L[3].value = True
                mixer.stop(wav7)

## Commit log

2026-03-19 Got schematic done
    [learnboard.kicad_pcb, learnboard.kicad_sch]
2026-03-20 day two
    worked on the pcb and fixed some things on the schematic
    [learnboard.kicad_pcb, learnboard.kicad_sch]
2026-03-21 tried to route things
    it is not going very well.
    [learnboard.kicad_pcb, learnboard.kicad_sch]
2026-03-25 Fixed lots of DRC errors and added mounting holes
    [learnboard.kicad_pcb, learnboard.kicad_sch]
2026-03-29 Worked on firmware.
    [learnboard-B_Cu.gbr, learnboard-B_Mask.gbr, learnboard-B_Paste.gbr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]
2026-03-30 Worked on firmware and webapp
    [learnboard.kicad_pcb, learnboard.kicad_sch]
2026-04-10 Finished readme and firmware.
    [Case.step, CaseTop.step, Connector.step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]
2026-04-10 Another update to organize the repo better and improve the readme.
    [BOM.csv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]
2026-04-19 updated BOM
    [BOM.csv]
2026-04-27 Updated Renders and BOM
    [BOM.csv]
2026-04-28 Organized the repo alittle bit
    [learnboard.kicad_pcb, learnboard.kicad_sch, switch.step]
2026-04-28 Added Gerber files
    [learnboard.kicad_pcb, learnboard.kicad_sch, switch.step]
2026-05-09 Updated the zine and the readme abit.
    [LightRender.blend, learnboard.kicad_pcb, learnboard.kicad_sch]
2026-05-25 Updated pcb to use the right diode footprints
    [learnboard-B_Cu.gbr, learnboard-B_Mask.gbr, learnboard-B_Paste.gbr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]
2026-05-26 Got the correct .step files.
    [Case.step, CaseTop.step, LightRender.blend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]
